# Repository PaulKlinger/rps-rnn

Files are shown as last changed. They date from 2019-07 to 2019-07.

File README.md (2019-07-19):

# RPS-RNN

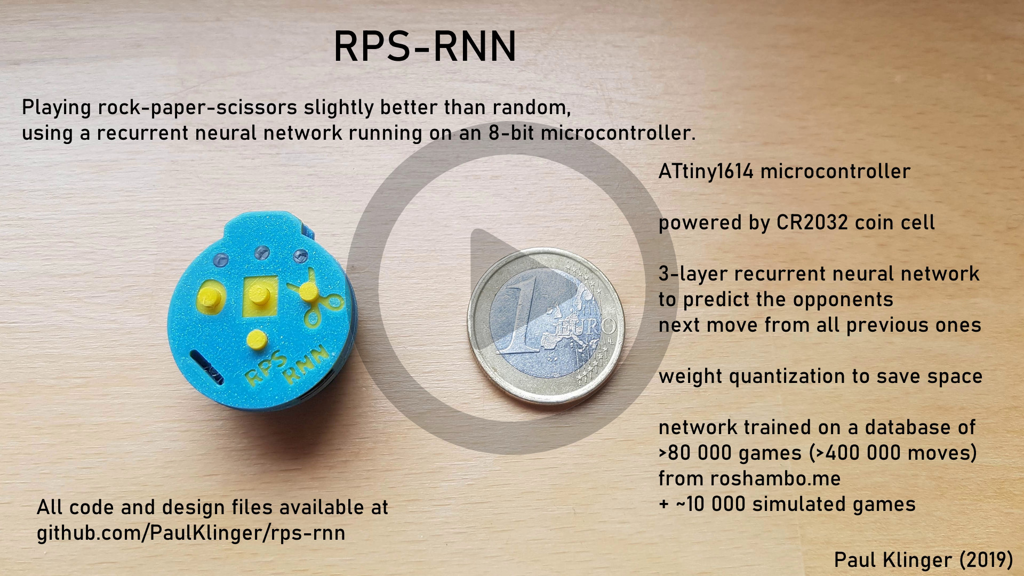
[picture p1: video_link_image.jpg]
(https://youtu.be/iuTKBHW0OaU "Project video")


The physical assembly of this project is pretty close to that of my [electronic dice](https://github.com/PaulKlinger/ndice). Some of the assembly tips there might also help here.

Components (mostly from aliexpress):
- 1 × [ATtiny1614 microcontroller](https://octopart.com/attiny1614-ssfr-microchip-82181131)
- [2mm PMMA optic fiber](https://www.aliexpress.com/item/5mX-Transparent-side-glow-plastic-PMMA-fiber-optic-cable-solid-core-optic-cable-diameter-2mm-3mm/32807597828.html)
- 1 × [10uf 0805 capacitor](https://www.aliexpress.com/item/100pcs-3-3PF-47UF-0805-SMD-100V-X7R-10-100nf-0-1uf-104K-104-22UF-4/32882102243.html)
- 3 × [10K 0805 resistor](https://www.aliexpress.com/item/100Pcs-0805-SMD-1-4W-0R-10M-chip-resistor-0-10R-100R-220R-330R-470R-1K/32858225842.html)
- 3 × [yellow 0805 LED](https://www.aliexpress.com/item/Free-Ship-100PCS-0805-light-emitting-diode-SMD-LED-bead-Red-Yellow-Green-White-Blue-Orange/32871959868.html)
- 1 × [coin cell battery holder](https://www.aliexpress.com/item/10PCS-Battery-Button-Cell-Holder-Socket-Case-CR2032-battery-holder-2032/32819924096.html)
- 3 × [smd switch](https://www.aliexpress.com/item/32752150129.html)
- 1 × [smd switch](https://www.aliexpress.com/item/32752118872.html)
- 1 × [smd slide switch](https://www.aliexpress.com/item/32967873133.html)

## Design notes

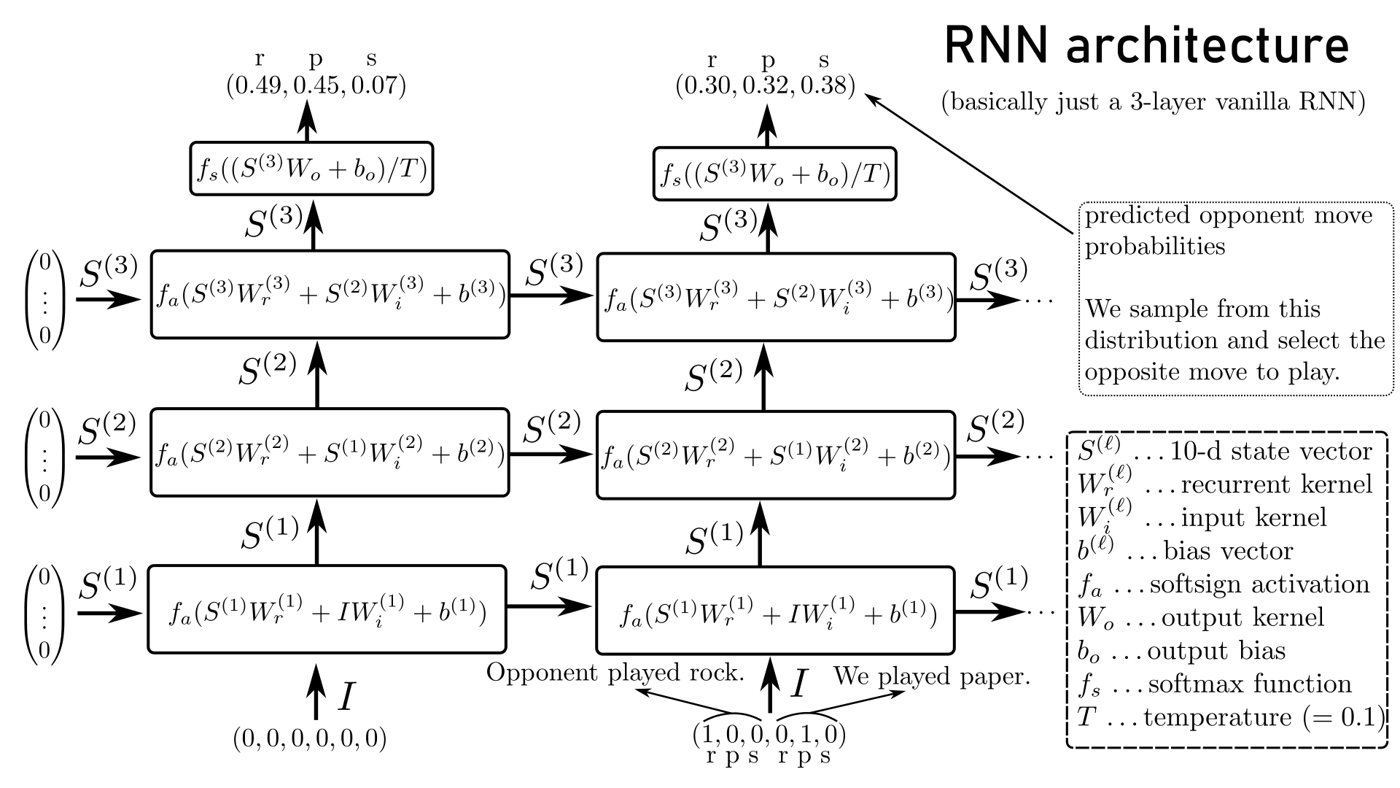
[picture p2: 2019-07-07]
diagrams/rnn_architecture.png

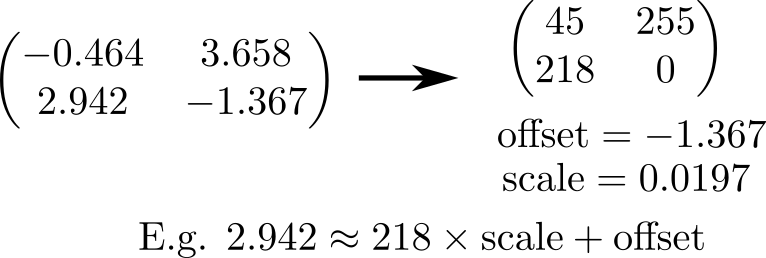
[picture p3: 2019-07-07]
diagrams/weight_quantization.png

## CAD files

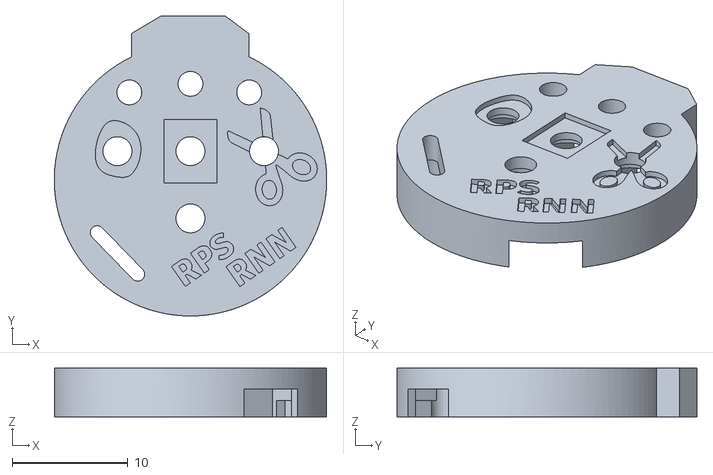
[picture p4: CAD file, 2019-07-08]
3d printed parts/top_cover.stl
23.5 x 25.9 x 4.20

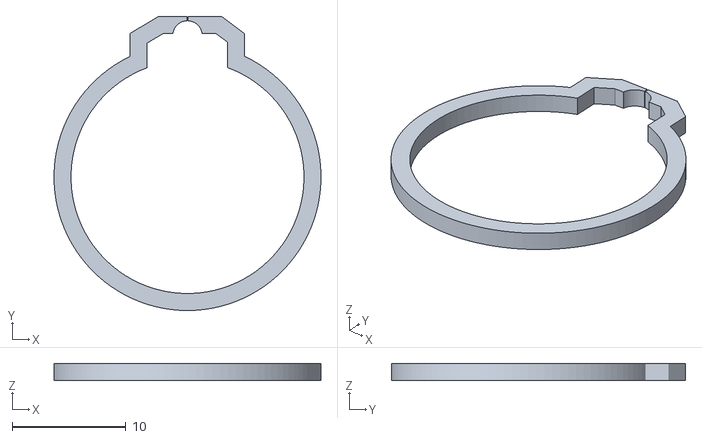
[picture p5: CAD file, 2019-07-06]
3d printed parts/spacer.stl
23.5 x 25.9 x 1.50

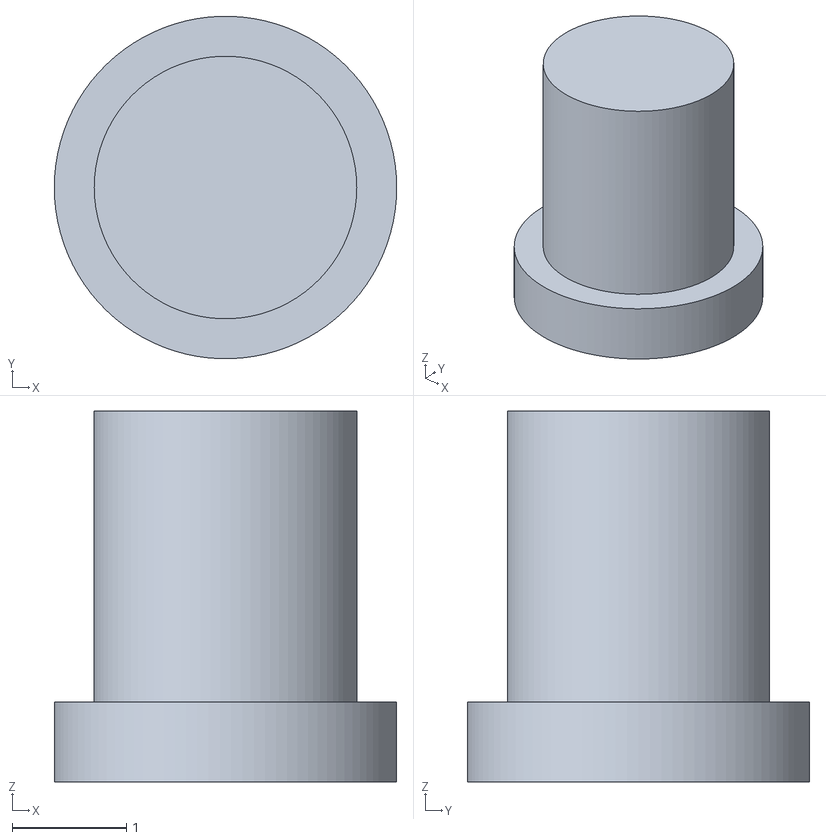
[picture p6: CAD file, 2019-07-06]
3d printed parts/rps_button.stl
3.00 x 3.00 x 3.25

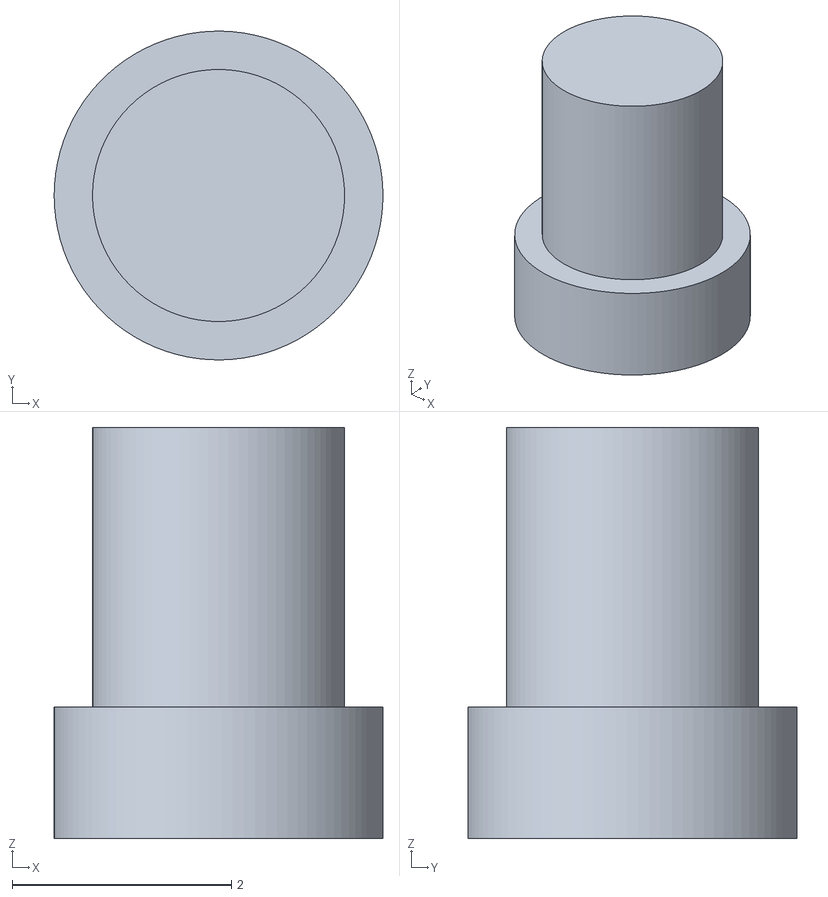
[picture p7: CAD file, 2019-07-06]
3d printed parts/start_button.stl
3.00 x 3.00 x 3.75

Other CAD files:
3d printed parts/rps_rnn.f3d

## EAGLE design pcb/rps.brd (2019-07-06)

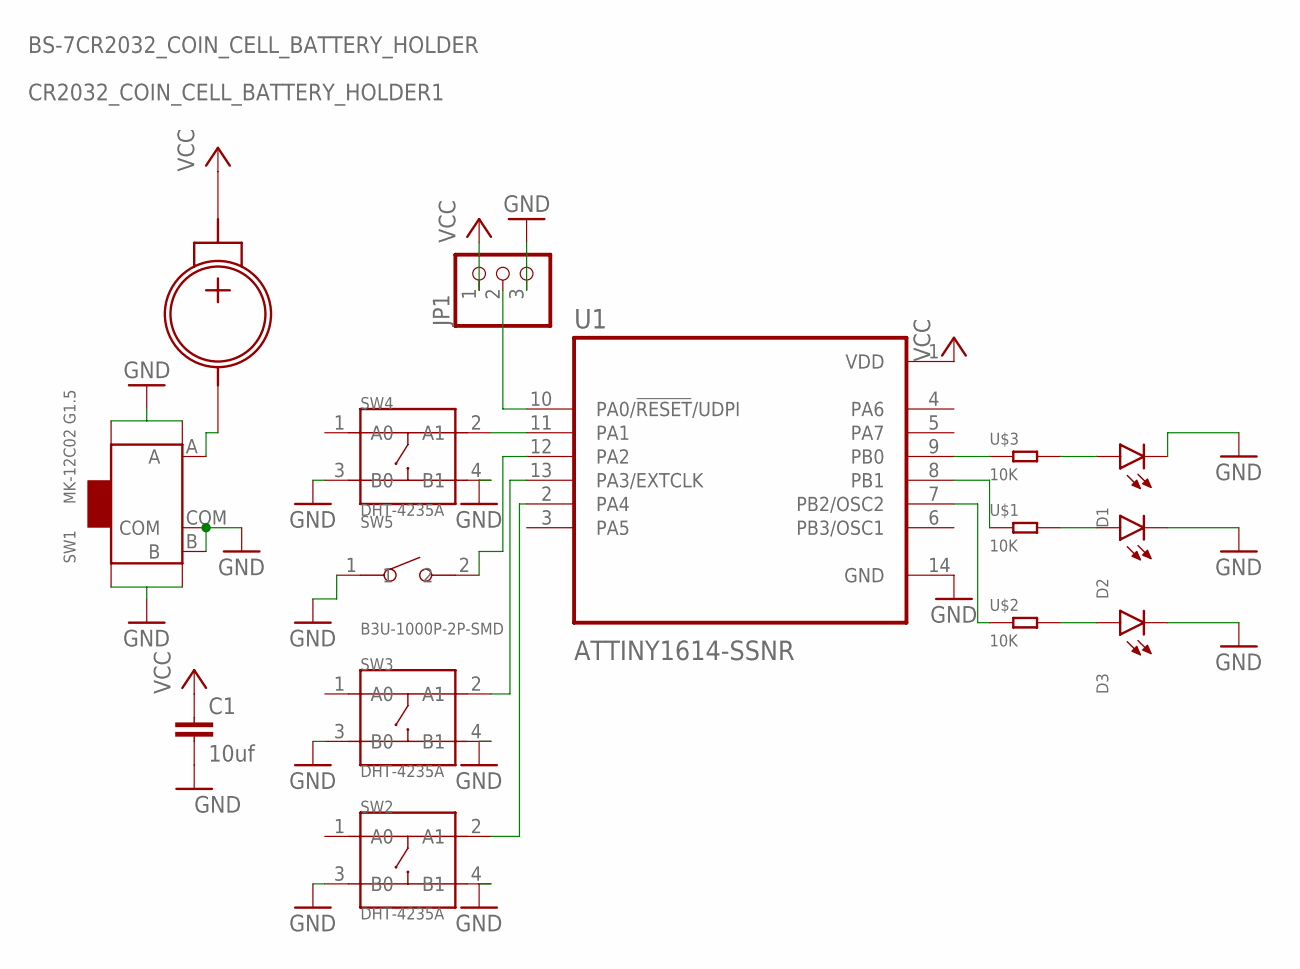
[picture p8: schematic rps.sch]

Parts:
C1: 10uf; C0805
CR2032_COIN_CELL_BATTERY_HOLDER1: BS-7CR2032_COIN_CELL_BATTERY_HOLDER; BS-7
D1, D2, D3: YELLOW-0805; SML0805
JP1: PINHD-1X3; 1X03
SW1: MK-12C02 G1.5; SW7-SMD-L6.7X2.7X3.2MM
SW2, SW3, SW4: DHT-4235A; SW4-SMD-4.2X3.2X2.5MM
SW5: B3U-1000P-2P-SMD; SW2-2.6-3.0X2.5X1.2+0.4MM
U1: ATTINY1614-SSNR; SOIC127P600X175-14N
U$1, U$2, U$3: 10K; R0805

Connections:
GND: C1.2, D1.C, D2.C, D3.C, JP1.3, SW1.B, SW1.COM, SW1.SS1, SW1.SS2, SW1.SS3, SW1.SS4, SW2.3 (B0), SW2.4 (B1), SW3.3 (B0), SW3.4 (B1), SW4.3 (B0), SW4.4 (B1), SW5.1, U1.14 (GND)
unnamed: JP1.2, U1.10 (PA0/!RESET!/UDPI)
unnamed: SW4.2 (A1), U1.11 (PA1)
unnamed: SW5.2, U1.12 (PA2)
unnamed: SW3.2 (A1), U1.13 (PA3/EXTCLK)
unnamed: SW2.2 (A1), U1.2 (PA4)
unnamed: U1.9 (PB0), U$3.1
unnamed: U1.8 (PB1), U$1.1
unnamed: U1.7 (PB2/OSC2), U$2.1
unnamed: D1.A, U$3.2
unnamed: D2.A, U$1.2
unnamed: D3.A, U$2.2
NEG: CR2032_COIN_CELL_BATTERY_HOLDER1.NEG, SW1.A
VCC: C1.1, CR2032_COIN_CELL_BATTERY_HOLDER1.POS, JP1.1, U1.1 (VDD)

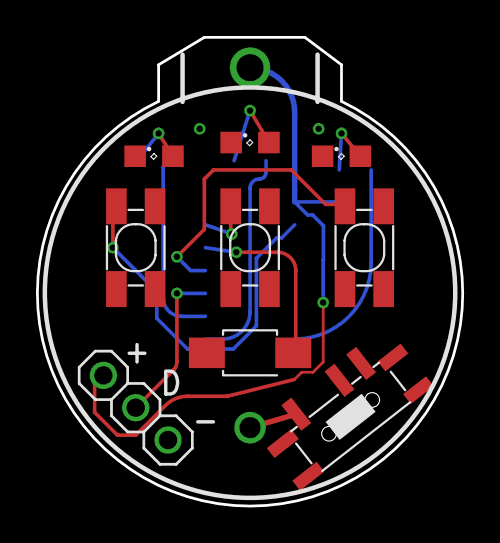
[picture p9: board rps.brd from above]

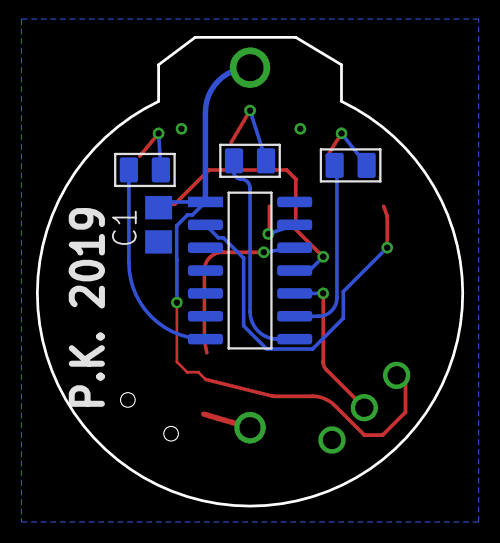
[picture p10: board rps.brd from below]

Board: 2 copper layers, 23.6 x 26.0 mm, 15 parts (5 on the bottom side), 14 nets.

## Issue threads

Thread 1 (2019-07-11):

2-pin tactile switch link in BOM

3amorphousblobs, 2019-07-11:
your BOM links to the same 4-pin switches for the start button as it does for the 3 other buttons.

PaulKlinger, 2019-07-19:
Thanks for the heads up, sorry I didn't see your comment before.

I've corrected the link, it should have pointed [here](https://www.aliexpress.com/item/32752118872.html).

(There isn't really any reason for using two different switches, I mostly wanted to try both of them out.)

3amorphousblobs, 2019-09-11:
Just got my first board populated/programmed and it works great! Awesome
project, I'll be giving out a bunch of these to coworkers, friends, etc.

On Fri, Jul 19, 2019 at 1:09 PM Paul Klinger <notifications@github.com>
wrote:

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

PaulKlinger, 2019-09-11:
That's awesome, this is the first time someone else actually built one of my projects! Please take some pictures :D

3amorphousblobs, 2019-09-13:
Here's the first one. I used super glue instead of the optical fiber for
the led diffusers. Other than that i followed all your instructions.

On Wed, Sep 11, 2019, 10:38 AM Paul Klinger <notifications@github.com>
wrote:

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

PaulKlinger, 2019-09-13:
The image didn't show up unfortunately, I think github just ignores email attachments.

3amorphousblobs, 2019-09-13:
Shoot, if you give me another email address ill send pics there

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

PaulKlinger, 2019-09-13:
klinger.paul@gmail.com (or you can upload a file to the issue on the github website)

3amorphousblobs, 2019-09-24:
[received_269599187256696.zip](https://github.com/PaulKlinger/rps-rnn/files/3647655/received_269599187256696.zip)

PaulKlinger, 2019-09-25:
Awesome :D

Did you have any issues building them? Maybe some things to change for v2?

Closed 2019-07-19.

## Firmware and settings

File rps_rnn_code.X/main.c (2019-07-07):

/*
 * File:   main.c
 * Author: Paul
 *
 * Created on June 23, 2019, 8:41 PM
 */

#include <avr/io.h>
#include "mcc_generated_files/config/clock_config.h"
#include "mcc_generated_files/mcc.h"
#include "mcc_generated_files/include/pin_manager.h"
#include <util/delay.h>
#include <stdlib.h>
#include <math.h>

#include "matrix.h"
#include "model_weights.h"

#include "model.h"

// WARNING!!! I changed "*link_data_start" in
//E:\Program Files (x86)\Microchip\MPLABX\v5.10\packs\Atmel\ATtiny_DFP\1.3.238\gcc\dev\attiny1614\device-specs\specs-attiny1614
// from "-Tdata 0x803800" to "	-Tdata 0x802000"
// this prevents a linker error for static or global variables.
// But I'm somewhat uncertain if this is actually correct.


#define TEMPERATURE 0.1

//LED pins:
// rock: PB0
// paper: PB1
// scissors: PB2

// button pins:
// rock: P4
// paper: PA3
// scissors: PA1
// start: PA2
static inline bool start_pressed() {return !IO_PA2_get_level();}
static inline bool rock_pressed() {return !IO_PA4_get_level();}
static inline bool paper_pressed() {return !IO_PA3_get_level();}
static inline bool scissors_pressed() {return !IO_PA1_get_level();}

static inline void set_led_rock(bool new_state) {IO_PB0_set_level(new_state);}
static inline void set_led_paper(bool new_state) {IO_PB1_set_level(new_state);}
static inline void set_led_scissors(bool new_state) {IO_PB2_set_level(new_state);}

static void set_all_leds(bool new_state) {
    set_led_rock(new_state);
    set_led_paper(new_state);
    set_led_scissors(new_state);
}

static inline void blink_all(uint8_t times, uint16_t dwell_ms) {
    for (; times > 0;times--){
        set_all_leds(1);
        _delay_ms(dwell_ms);
        set_all_leds(0);
        _delay_ms(dwell_ms);
    }
}

static void display_move(rps move) {
    set_all_leds(false);
    switch (move) {
        case ROCK:
            set_led_rock(true);
            break;
        case PAPER:
            set_led_paper(true);
            break;
        case SCISSORS:
            set_led_scissors(true);
            break;
        case START:
            break;
    }
}

rps get_selected_move() {
    if (rock_pressed()) {
        return ROCK;
    } else if (paper_pressed()) {
        return PAPER;
    } else if (scissors_pressed()) {
        return SCISSORS;
    } else {
        return START;
    }
}

void play_against_rps_rnn() {
    // human player plays against device
    // pressing start starts a countdown until device move is shown
    // then player move needs to be entered before start can be pressed again
    
    blink_all(2, 100);
    
    rps our_move = START;
    rps opponent_move = START;
    bool opponent_move_entered = true;
    
    while (1){
        if (start_pressed() && opponent_move_entered) {
            if (opponent_move == START) {
                // if this is the first move seed the RNG
                // with the current time (from RTC counter)
                srandom(RTC.CNT);
                random();
            }
            our_move = model_predict(opponent_move, TEMPERATURE);
            blink_all(3, 200);
            display_move(our_move);
            opponent_move_entered = false;
        } else {
            rps selected_move = get_selected_move();
            if (selected_move != START) {
                opponent_move = selected_move;
                opponent_move_entered = true;
            }
        }
        _delay_ms(10);
    }
}

void play_with_rps_rnn() {
    // use device to suggest moves against human opponent
    // entering opponents move immediately suggests next move
    
    // Wait until start button is released
    // This gives some randomness to seed the RNG
    while (start_pressed()){};
    // seed the RNG with the current time (from RTC counter)
    srandom(RTC.CNT);
    
    display_move(model_predict(START, TEMPERATURE));
    rps selected_move;
    while (1) {
        // need to save selected move, otherwise it could change between
        // condition evaluation and prediction
        selected_move = get_selected_move();
        if (selected_move != START) {
            // blink the LED so it's obviously a new move even if the
            // new suggestion is the same as the old one
            set_all_leds(0);
            _delay_ms(100);
            display_move(model_predict(selected_move, TEMPERATURE));
            // wait until button is released + a bit for bouncing
            while (get_selected_move() != START){}
            _delay_ms(100);
        }
        _delay_ms(10);
    }
}

int main(void)
{
    /* Initializes MCU, drivers and middleware */
    SYSTEM_Initialize();
    // wait a bit to avoid spurious input on startup
    _delay_ms(100);
    // choose device mode depending on whether start is pressed
    if (start_pressed()) {
        play_with_rps_rnn();
    } else {
        play_against_rps_rnn();
    }
}

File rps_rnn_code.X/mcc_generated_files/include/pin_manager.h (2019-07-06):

/*
    (c) 2018 Microchip Technology Inc. and its subsidiaries. 
    
    Subject to your compliance with these terms, you may use Microchip software and any 
    derivatives exclusively with Microchip products. It is your responsibility to comply with third party 
    license terms applicable to your use of third party software (including open source software) that 
    may accompany Microchip software.
    
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
    IN NO EVENT WILL MICROCHIP BE LIABLE FOR ANY INDIRECT, SPECIAL, PUNITIVE, 
    INCIDENTAL OR CONSEQUENTIAL LOSS, DAMAGE, COST OR EXPENSE OF ANY KIND 
    WHATSOEVER RELATED TO THE SOFTWARE, HOWEVER CAUSED, EVEN IF MICROCHIP 
    HAS BEEN ADVISED OF THE POSSIBILITY OR THE DAMAGES ARE FORESEEABLE. TO 
    THE FULLEST EXTENT ALLOWED BY LAW, MICROCHIP'S TOTAL LIABILITY ON ALL 
    CLAIMS IN ANY WAY RELATED TO THIS SOFTWARE WILL NOT EXCEED THE AMOUNT 
    OF FEES, IF ANY, THAT YOU HAVE PAID DIRECTLY TO MICROCHIP FOR THIS 
    SOFTWARE.
*/
#ifndef PINS_H_INCLUDED
#define PINS_H_INCLUDED

#include "port.h"
/**
 * \brief Set IO_PA2 pull mode
 *
 * Configure pin to pull up, down or disable pull mode, supported pull
 * modes are defined by device used
 *
 * \param[in] pull_mode Pin pull mode
 */
static inline void IO_PA2_set_pull_mode(const enum port_pull_mode pull_mode)
{
	PORTA_set_pin_pull_mode(2, pull_mode);
}

/**
 * \brief Set IO_PA2 data direction
 *
 * Select if the pin data direction is input, output or disabled.
 * If disabled state is not possible, this function throws an assert.
 *
 * \param[in] direction PORT_DIR_IN  = Data direction in
 *                      PORT_DIR_OUT = Data direction out
 *                      PORT_DIR_OFF = Disables the pin
 *                      (low power state)
 */
static inline void IO_PA2_set_dir(const enum port_dir dir)
{
	PORTA_set_pin_dir(2, dir);
}

/**
 * \brief Set IO_PA2 input/sense configuration
 *
 * Enable/disable IO_PA2 digital input buffer and pin change interrupt,
 * select pin interrupt edge/level sensing mode
 *
 * \param[in] isc PORT_ISC_INTDISABLE_gc    = Interrupt disabled but input buffer enabled
 *                PORT_ISC_BOTHEDGES_gc     = Sense Both Edges
 *                PORT_ISC_RISING_gc        = Sense Rising Edge
 *                PORT_ISC_FALLING_gc       = Sense Falling Edge
 *                PORT_ISC_INPUT_DISABLE_gc = Digital Input Buffer disabled
 *                PORT_ISC_LEVEL_gc         = Sense low Level
 */
static inline void IO_PA2_set_isc(const PORT_ISC_t isc)
{
	PORTA_pin_set_isc(2, isc);
}

/**
 * \brief Set IO_PA2 inverted mode
 *
 * Enable or disable inverted I/O on a pin
 *
 * \param[in] inverted true  = I/O on IO_PA2 is inverted
 *                     false = I/O on IO_PA2 is not inverted
 */
static inline void IO_PA2_set_inverted(const bool inverted)
{
	PORTA_pin_set_inverted(2, inverted);
}

/**
 * \brief Set IO_PA2 level
 *
 * Sets output level on a pin
 *
 * \param[in] level true  = Pin level set to "high" state
 *                  false = Pin level set to "low" state
 */
static inline void IO_PA2_set_level(const bool level)
{
	PORTA_set_pin_level(2, level);
}

/**
 * \brief Toggle output level on IO_PA2
 *
 * Toggle the pin level
 */
static inline void IO_PA2_toggle_level()
{
	PORTA_toggle_pin_level(2);
}

/**
 * \brief Get level on IO_PA2
 *
 * Reads the level on a pin
 */
static inline bool IO_PA2_get_level()
{
	return PORTA_get_pin_level(2);
}
/**
 * \brief Set IO_PB2 pull mode
 *
 * Configure pin to pull up, down or disable pull mode, supported pull
 * modes are defined by device used
 *
 * \param[in] pull_mode Pin pull mode
 */
static inline void IO_PB2_set_pull_mode(const enum port_pull_mode pull_mode)
{
	PORTB_set_pin_pull_mode(2, pull_mode);
}

/**
 * \brief Set IO_PB2 data direction
 *
 * Select if the pin data direction is input, output or disabled.
 * If disabled state is not possible, this function throws an assert.
 *
 * \param[in] direction PORT_DIR_IN  = Data direction in
 *                      PORT_DIR_OUT = Data direction out
 *                      PORT_DIR_OFF = Disables the pin
 *                      (low power state)
 */
static inline void IO_PB2_set_dir(const enum port_dir dir)
{
	PORTB_set_pin_dir(2, dir);
}

/**
 * \brief Set IO_PB2 input/sense configuration
 *
 * Enable/disable IO_PB2 digital input buffer and pin change interrupt,
 * select pin interrupt edge/level sensing mode
 *
 * \param[in] isc PORT_ISC_INTDISABLE_gc    = Interrupt disabled but input buffer enabled
 *                PORT_ISC_BOTHEDGES_gc     = Sense Both Edges
 *                PORT_ISC_RISING_gc        = Sense Rising Edge
 *                PORT_ISC_FALLING_gc       = Sense Falling Edge
 *                PORT_ISC_INPUT_DISABLE_gc = Digital Input Buffer disabled
 *                PORT_ISC_LEVEL_gc         = Sense low Level
 */
static inline void IO_PB2_set_isc(const PORT_ISC_t isc)
{
	PORTB_pin_set_isc(2, isc);
}

/**
 * \brief Set IO_PB2 inverted mode
 *
 * Enable or disable inverted I/O on a pin
 *
 * \param[in] inverted true  = I/O on IO_PB2 is inverted
 *                     false = I/O on IO_PB2 is not inverted
 */
static inline void IO_PB2_set_inverted(const bool inverted)
{
	PORTB_pin_set_inverted(2, inverted);
}

/**
 * \brief Set IO_PB2 level
 *
 * Sets output level on a pin
 *
 * \param[in] level true  = Pin level set to "high" state
 *                  false = Pin level set to "low" state
 */
static inline void IO_PB2_set_level(const bool level)
{
	PORTB_set_pin_level(2, level);
}

/**
 * \brief Toggle output level on IO_PB2
 *
 * Toggle the pin level
 */
static inline void IO_PB2_toggle_level()
{
	PORTB_toggle_pin_level(2);
}

/**
 * \brief Get level on IO_PB2
 *
 * Reads the level on a pin
 */
static inline bool IO_PB2_get_level()
{
	return PORTB_get_pin_level(2);
}
/**
 * \brief Set IO_PA1 pull mode
 *
 * Configure pin to pull up, down or disable pull mode, supported pull
 * modes are defined by device used
 *
 * \param[in] pull_mode Pin pull mode
 */
static inline void IO_PA1_set_pull_mode(const enum port_pull_mode pull_mode)
{
	PORTA_set_pin_pull_mode(1, pull_mode);
}

/**
 * \brief Set IO_PA1 data direction
 *
 * Select if the pin data direction is input, output or disabled.
 * If disabled state is not possible, this function throws an assert.
 *
 * \param[in] direction PORT_DIR_IN  = Data direction in
 *                      PORT_DIR_OUT = Data direction out
 *                      PORT_DIR_OFF = Disables the pin
 *                      (low power state)
 */
static inline void IO_PA1_set_dir(const enum port_dir dir)
{
	PORTA_set_pin_dir(1, dir);
}
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

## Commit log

2019-06-27 added pcbs
    [rps.brd, rps.sch]
2019-06-27 initial commit of code, currently just experiments
2019-07-03 fixed a bunch of stupid errors in simple model calculation
    first move gives correct result now, with some inaccuracies due to tanh (will replace with softsign)
    still need to test later moves and sampling
    [main.c]
2019-07-03 seed random number generator, bugfix
    sampling seems to work
    [main.c]
2019-07-03 corrected temperature (was inverted), prevent overflow in softmax
    [main.c]
2019-07-05 set up pins correctly, added code in main.c for assembly testing
    [main.c, pin_manager.h]
2019-07-06 working main loop, seeding of RNG from timer
2019-07-06 adjusted pad sizes for buttons on PCB
    [rps.brd, rps.sch]
2019-07-06 Added 3d printed parts and Fusion 360 model
    [rps_button.stl, rps_rnn.f3d, spacer.stl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]
2019-07-06 added gerbers
    [rps.GBL, rps.GBO, rps.GBP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]
2019-07-07 use expected score to select which move to play
    Instead of just playing the move that does best
    against the predicted one, use all the information available
    in the predicted probabilities to select the one that
    optimizes the expected score. E.g. when the predicted
    probabilities for opponent move are (0.1,0.44,0.46) play
    scissors instead of rock.
    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
2019-07-07 changed temperature back from testing value
2019-07-08 minor changes to top cover model
    [rps_rnn.f3d, top_cover.stl]
